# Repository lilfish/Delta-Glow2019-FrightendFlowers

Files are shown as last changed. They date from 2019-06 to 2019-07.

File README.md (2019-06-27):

# Glow-2019 - Frightend flowers

## Concept - the story

There was this biologist and he got bullied a lot when he was younger, the only way he found peace and comfort was by talking to his plants. The plants wouldn’t call him names or judge him.
 
But, after a while he got bored. He would share all his problems with the plants, but the plants couldn’t share theirs. He started to do experiments with the plants, with an effort to get to know the plants better.
 
After a while, he found a way to make the plants communicate with each other through light. The biologist now made visual what was going on with the plants; not only for the plants themselves but also for the eyes of the people.
 
While the biologist observed the communications, something strange happened. When the biologist was a few meters away, the plants would very calmly and rarely communicate with each other. But, when the biologist came close, the plants would go wild.
 
The biologist did not understand why and tried to figure it out. He put the plants on the floor close to his desk, and observe tirelessly until he knew what was going on.
 
After a while, he would notice something strange. When he was extremely close to a plant for a while, he noticed that that plants would suddenly stop communicating. It would take a while when they started again, and in the meantime, they wouldn’t grow. And then he knew.
 
The plants were terrified of him. Because they were afraid, they let each other know a human was near. 

The biologist was very shocked by this. So much that he decided he had to let the entire world know what was going on. This led to the creation of Frightened Flowers

## Concept - in depth

There will be multiple frames holding flower pots. Each flower pot will have a led strip to light up the flower and the pot on the outside/inside.

On top of the frame there is a motor that can lift the flower pot (with flower inside it) up and down. The motor is also able to shake the flower a bit when it's frightend.

There are also led strips sticking out of a flowerpot going to the next flower pot. These are "communication leds" and will visualize the effect of the plants talking to each other. The pots will light up or have another cool effect when a plant receives a "light pulse".

The flowers should probably also have a small vibration motor to vibrate the leaves and flower itself. This is to show the frightend effect.

## Documentation & workflow

All the documentation can be found in the git wiki found [here](https://git.fhict.nl/I393504/glow-2019/wikis/home)

As for the workflow: there are 4 main branches. These are

* Release
* Master
* Untested
* Others

**Release**\
When you have tested your code and it works on a frame and/or with multiple frames, you can move it to the Release. This is the code that will be uploaded to the arduinos. 

**Master**\
This will have all the final code, before getting tested for release.

**Untested**\
When you are done with an example code and want to intergrate it with the main code, you can add this to the untested. This code should be tested on a frame before moving to the Release folder.

**Others**\
This folder is for everything not code related. These can be presentation files, frame blueprints and the 3D case plans. For each item you can make a new folder and upload it in there. This way this project doesnt need a drive when giving it to other students.
In this folder you are also allowed to make new folders with your name. In the folder you just created you can store example code. These example codes are codes that can run on a arduino stand-alone, but not yet in the final version.

Currently we have two arduino's per frame. Thats why you can find two folders inside the Untested and Release folder. These are called ``motorSensorController`` and ``ledstripController``. The motorSensorController is the motor & sensor arduino. The ledstripController is the code for the arduino inside the flower pot which will emit light effects and such.

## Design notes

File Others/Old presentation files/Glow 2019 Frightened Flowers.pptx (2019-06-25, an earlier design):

## Glow 2019 Frightened Flowers

Davey Hurkmans, Geert Boer, Jane Buzykina & Vincent Venhuizen

## KNOWN PROBLEMS & FIXES

- Motor - Problems for demo
- Frame - Needs to be built more stable
- LED strips - Couldn't order new ones (re-used old one's)
- Animations - Require fine tuning

## DEMO

We start with a small demo of our project.

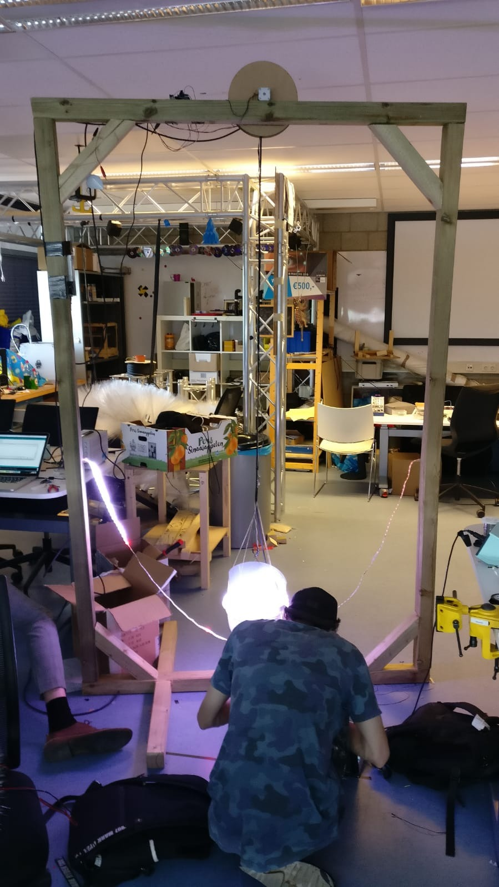
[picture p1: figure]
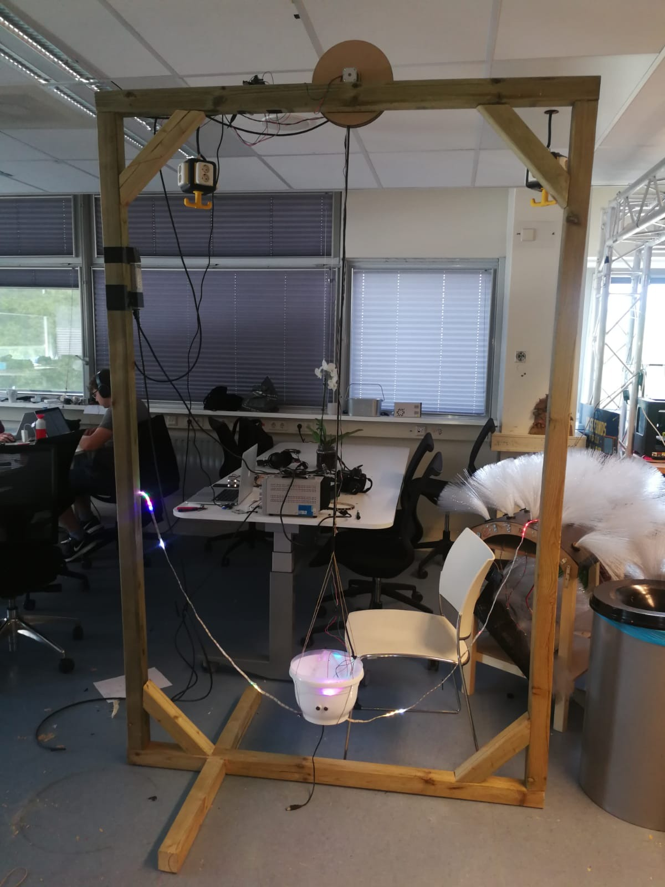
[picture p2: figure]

## COSTS

- Wooden frame - €60 +- /per frame
- LED strips 5M - €20 +- /1x
- Stepper motor - €40 +- /1x
- Power supply - €12 +- /1x
- Flower pot - €10 +- /1x
Total per frame: €140
I.e. 7 frames: €994

## Thanks for listening!

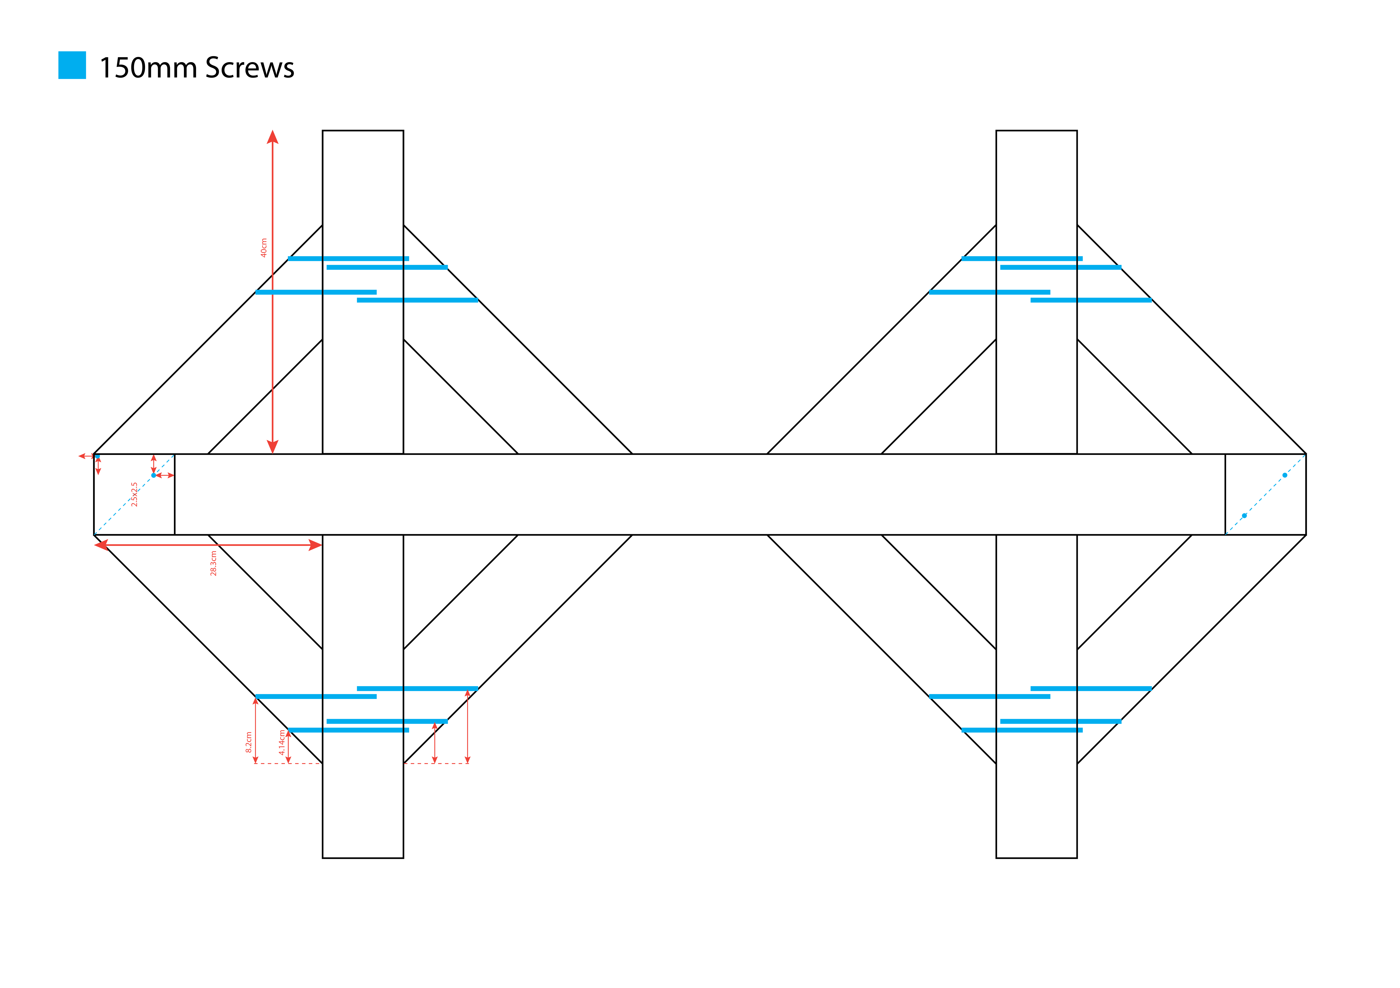
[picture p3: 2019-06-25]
Others/Frame blueprints/Frame blueprints - feet view.png

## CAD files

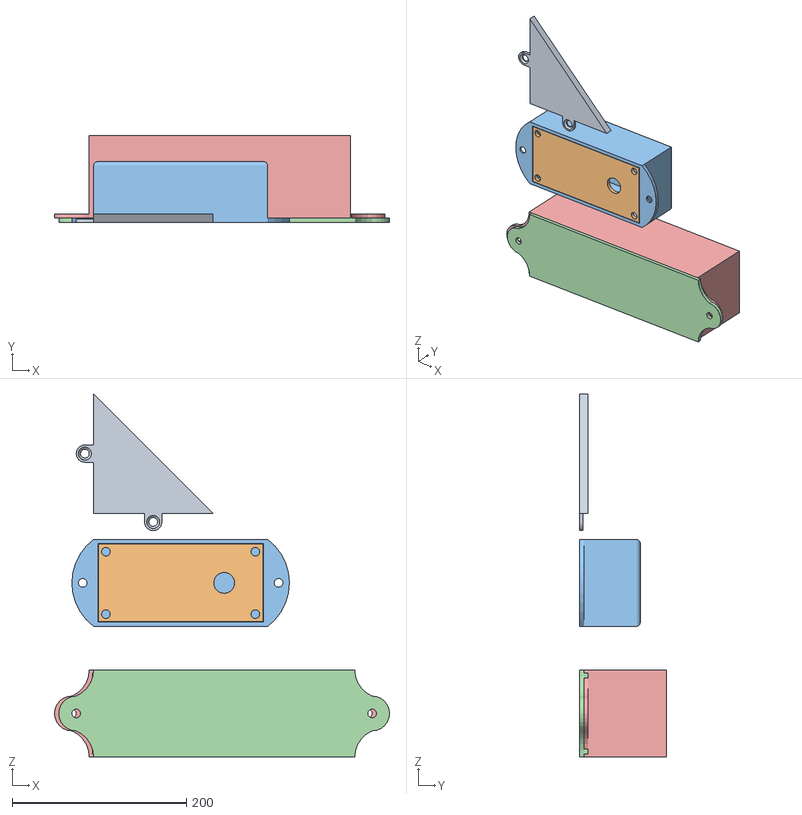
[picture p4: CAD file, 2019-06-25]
Others/Case plans (3D files)/Glow_casings v2.obj
385.0 x 100.0 x 417.0
Electronic case cap
motor_case_floor
motor_case_cap
powerSuply_floor
powerSuply_cap

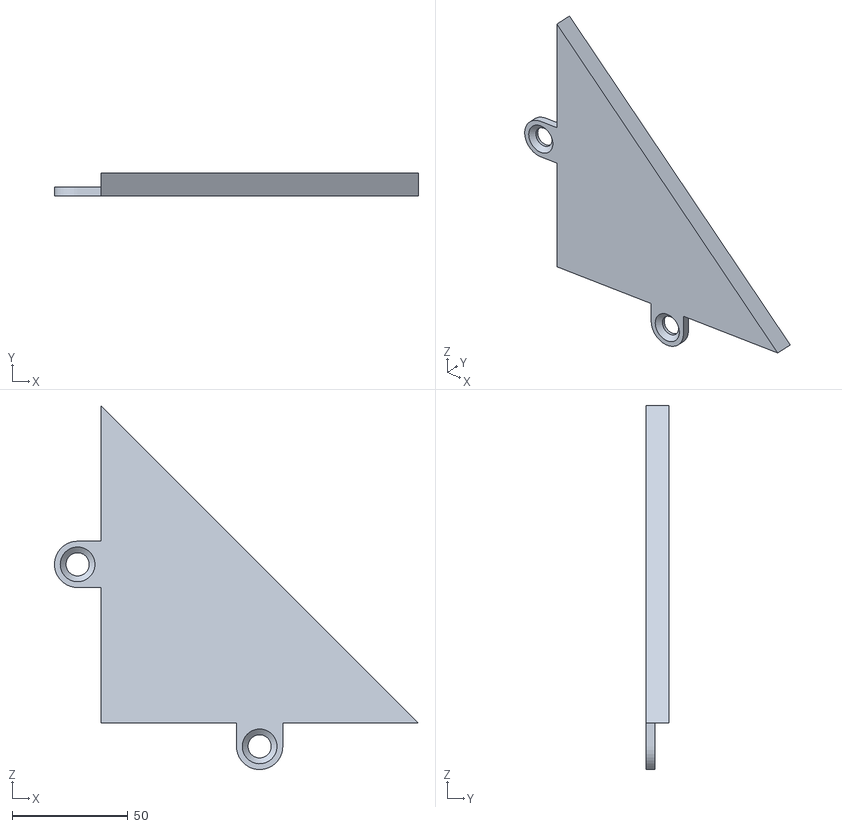
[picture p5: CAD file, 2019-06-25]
Others/Case plans (3D files)/STL files/Electronic case cap.stl
157.0 x 10.0 x 157.0

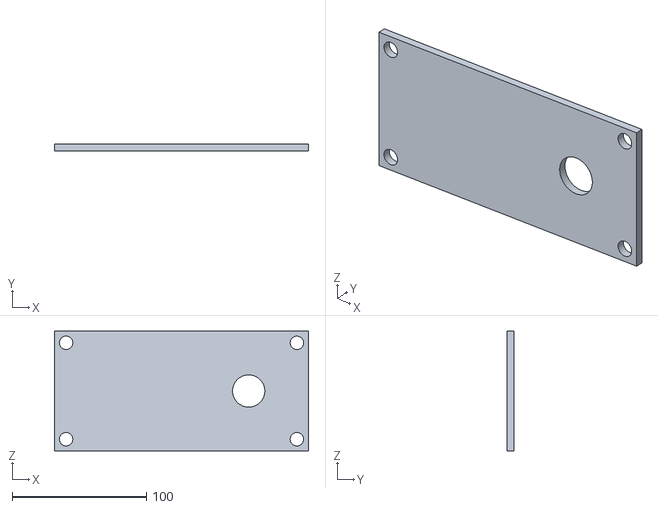
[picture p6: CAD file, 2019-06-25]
Others/Case plans (3D files)/STL files/motor_case_floor.stl
189.0 x 5.00 x 89.0

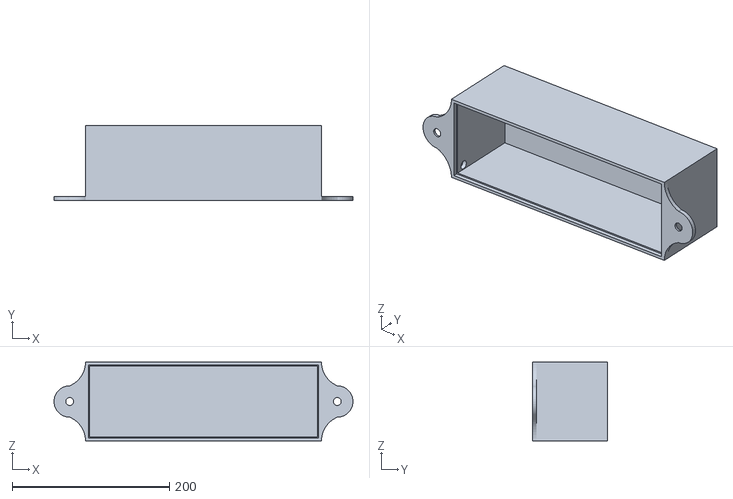
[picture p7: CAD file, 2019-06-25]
Others/Case plans (3D files)/STL files/powerSuply_cap.stl
380.0 x 95.0 x 100.0

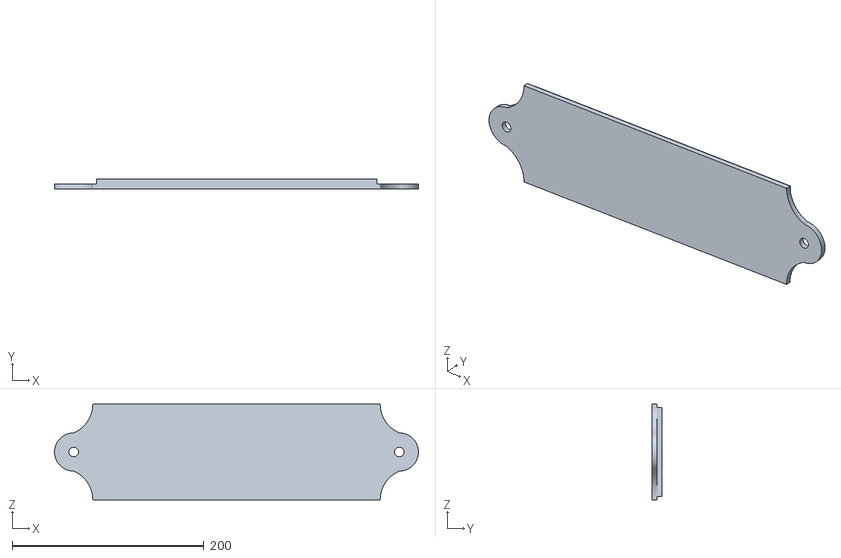
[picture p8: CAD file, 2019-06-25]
Others/Case plans (3D files)/STL files/powerSuply_floor.stl
380.0 x 10.0 x 100.0

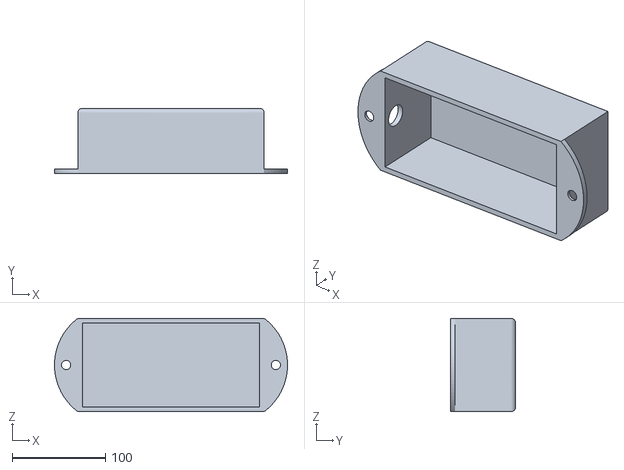
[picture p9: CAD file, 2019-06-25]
Others/Case plans (3D files)/STL files/motor_case_cap.stl
249.9 x 70.0 x 100.0

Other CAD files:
Others/Case plans (3D files)/Glow_casings v2.f3d

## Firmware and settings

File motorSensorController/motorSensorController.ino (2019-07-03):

#include "Enums.hpp"

#include "IMotor.hpp"
#include "StepperMotor.hpp"

StepperMotor motor(200, 8, 9, 10, 11);

int maxHeight = 2700;
void setup()
{
  // put your setup code here, to run once:
  Serial.begin(9600);
  motor.GoToHeight(maxHeight - 300);
}


void loop()
{
  motor.GoToHeight(maxHeight);
  delay(2000);
  motor.FallDown();
  motor.GoToHeight(maxHeight - 300);
  for (int i = 0; i < 40; i++)
  {
    motor.Shake(50);
  }
}

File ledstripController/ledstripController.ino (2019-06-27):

#define DEBUG

#include "Enums.hpp"

#include "ICommunicator.hpp"
#include "ILedstrip.hpp"
#include "IDistanceSensor.hpp"

#include "SerialCommunicator.hpp"
#include "WS2812Strip.hpp"
#include "UltrasonicDistanceSensor.hpp"

#define STRIP_SIZE 30
#define STRIP_PIN 12

ICommunicator* communicator;
ILedstrip* strip;

IDistanceSensor* sensor;



CRGB Leds[STRIP_SIZE];

void setup() {
  // put your setup code here, to run once:
  communicator = new SerialCommunicator(9600);
  sensor = new UltrasonicDistanceSensor(9, 10);

  FastLED.addLeds<WS2812B, STRIP_PIN, RGB>(Leds, STRIP_SIZE);

  
  strip = new WS2812Strip(Leds,STRIP_SIZE);

  #ifdef DEBUG
  Serial.println("Started");
  #endif
}


States state = UNINITIALIZED;
void loop() {
  // put your main code here, to run repeatedly:
  

  //check what state it should be in


  state = sensor->GetState();


  
  Serial.println(state);
  strip->SetState(state);
}

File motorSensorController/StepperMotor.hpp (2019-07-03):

#pragma once

#include "Enums.hpp"
#include <Stepper.h>

class StepperMotor
{
  private:
    Stepper* stepper;
    int currentHeight;

    int m1a;
    int m1b;
    int m2a;
    int m2b;
  public:
    StepperMotor(int stepsPerRev, int m1a, int m1b, int m2a, int m2b);
    void Update();
    void SetState(States state);
    float CalculateHeight(float restlesness);
    ~StepperMotor();

    bool GoToHeight(int height);
    int CurrentHeight();
    bool Shake(int intensity);
    void FallDown();
};

StepperMotor::StepperMotor(int stepsPerRev, int m1a, int m1b, int m2a, int m2b)
{
  stepper = new Stepper(stepsPerRev, m1a, m1b, m2a, m2b);
  stepper->setSpeed(170);

  pinMode(m1a, OUTPUT);
  pinMode(m1b, OUTPUT);
  pinMode(m2a, OUTPUT);
  pinMode(m2b, OUTPUT);

  this->m1a = m1a;
  this->m1b = m1b;
  this->m2a = m2a;
  this->m2b = m2b;

  currentHeight = 0;
}

StepperMotor::~StepperMotor()
{
  delete stepper;
}

bool StepperMotor::GoToHeight(int height)
{
  int posToMove = height - currentHeight;
  stepper->step(posToMove);
  currentHeight = height;
  return true;
}

bool StepperMotor::Shake(int intensity)
{
  stepper->step(intensity);
  stepper->step(-1 * intensity);
  return true;
}

int StepperMotor::CurrentHeight()
{
  return currentHeight;
}

void StepperMotor::FallDown()
{
  digitalWrite(m1a, LOW);
  digitalWrite(m1b, LOW);
  digitalWrite(m2a, LOW);
  digitalWrite(m2b, LOW);
  currentHeight = 0;
  delay(8000);
}

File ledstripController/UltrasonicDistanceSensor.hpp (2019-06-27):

#pragma once

#include "IDistanceSensor.hpp"
#include "Enums.hpp"

class UltrasonicDistanceSensor : public IDistanceSensor
{
private: //HIER STAAN JE VARIABELEN DIE OVER DE HELE CLASS BESCHIKBAAR MOETEN ZIJN, MAAR NIET ERBUITEN
    int trigPin;
    int echoPin;

    int sensitivity = 5;

    int restlessness = 0;

    float y;

    States oldState;
    

  
    States calculateState();
    int getDistance();

public: // HIER STAAND DE VARIABELEN DIE ZOWEL BINNEN ALS BUITEN DE CLASS BESCHIKBAAR MOETEN ZIJN
    int UpdateRestlessness(int distance);
    States GetState();
    UltrasonicDistanceSensor(int trigPin, int echoPin);
    ~UltrasonicDistanceSensor(); // <-- NEGEER DEZE MAAR VINCENT

};

UltrasonicDistanceSensor::UltrasonicDistanceSensor(int trigPin, int echoPin)
{
    this->trigPin = trigPin;
    this->echoPin = echoPin;
    pinMode(trigPin, OUTPUT);
    pinMode(echoPin, INPUT);
    oldState = UNINITIALIZED;
}

UltrasonicDistanceSensor::~UltrasonicDistanceSensor() {} // <-- NEGEER DEZE OOK MAAR VINCENT

int UltrasonicDistanceSensor::getDistance()
{
    //States currentState = CALM;
    digitalWrite(trigPin, LOW);
    delayMicroseconds(2);

    digitalWrite(trigPin, HIGH);
    delayMicroseconds(10);
    digitalWrite(trigPin, LOW);
    // DO STUFF
    long measuredDuration = pulseIn(echoPin, HIGH);

    float measuredDistance = measuredDuration * 0.034 / 2;
    // Prints the distance on the Serial Monitor
    return (int)measuredDistance;
}


int UltrasonicDistanceSensor::UpdateRestlessness(int distance)
{   // SEE WIKI FOR EXPLANATION: https://git.fhict.nl/I393504/glow-2019/wikis/%5BPROGRAMMING%5D-How-the-sensor-calculates-the-state
    if(oldState == UNINITIALIZED)
    {
        oldState = CALM;
    }

    if (distance <= 250)
    {
        y = sensitivity - (float(sensitivity) / 250 * distance);

        if (oldState == CALM)
        {
            restlessness += y;
        }
        else if (oldState == RESTLESS1)
        {
            restlessness += (y + 1);
        }
        else if (oldState == RESTLESS2)
        {
            restlessness += (y + 2);
        }
        else if (oldState == RESTLESS3)
        {
            restlessness += (y + 3);
        }
    }
    else if (restlessness > 0)
    {
        restlessness -= 4;
    }
    if (restlessness < 0)
    {
        restlessness = 0;
    }
    
    #ifdef DEBUG
    Serial.print("Calculaterestlessness @  restlessness: ");
    Serial.println(restlessness);
    Serial.print("Calculaterestlessness @  distance: ");
    Serial.println(distance);
    Serial.print("Calculaterestlessness @  state: ");
    Serial.println((States)oldState);
    Serial.println("");
    #endif

    return restlessness;
}

States UltrasonicDistanceSensor::calculateState()
{   // SEE WIKI FOR EXPLANATION: https://git.fhict.nl/I393504/glow-2019/wikis/%5BPROGRAMMING%5D-How-the-sensor-calculates-the-state

    if (restlessness < 0)
    {
        return CALM;
    }

    States newState = CALM;

    if (restlessness > 0 && restlessness <= 100)
    {
        newState = (States)CALM;
    }
    else if (restlessness > 100 && restlessness <= 200)
    {
        newState = (States)RESTLESS1;
    }
    else if (restlessness > 200 && restlessness <= 300)
    {
        newState = (States)RESTLESS2;
    }
    else if (restlessness > 300 && restlessness <= 400)
    {
        newState = (States)RESTLESS3;
    }
    else if (restlessness > 400)
    {
        newState = (States)OUT;
    }

    oldState = newState;
    return newState;
}

States UltrasonicDistanceSensor::GetState()
{
    int distance = getDistance();
    UpdateRestlessness(distance);
    // private restlessness is updated and used by calculateState
    States state = calculateState();
    return state;
}

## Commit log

2019-06-17 Old demo code
    it pushes 2 leds colored over the led strip
2019-06-17 ledstripcontroller code added
2019-06-17 Worked on communication for ledstrip
    Only the return currentstate not working yet
    [ledstripController.ino, motorSensorController.ino]
2019-06-17 Fixed communication on mega
    Listen to Serial1 for input from the arduino uno.
    Changes state when input contains "s + int(1-5)"
    [motorSensorController.ino]
2019-06-17 Big update on motorSensorController
    Added debug mode
    Added the hc-srd1 read function in the Distance class
    Added a restless function in the Distance class
    Added a calculation function in the Motor class
2019-06-18 Worked on the led strip communication
    Communication broke, fixed but don't know why it broke.
    Added a big comment in ledstripController/ledstripController.ino - Check it please
    [WS2812Strip.hpp, ledstripController.ino]
2019-06-25 Fixed detection module
    Added an example sensor code. In here I made the concept and tested it with a potmeter.
    Added the final code from example to the main code in Release.
    [SensorCode.ino]
2019-06-25 Removed the ledstrip files from motor
    Ledstrips are not used in the motor arduino code. Removed these
2019-06-25 Added others folder
    In others you can find the presentation files, frame blueprints and 3D models
    Added a readme for this folder so it's clear where we use it for.
    [Electronic case cap.stl, Glow_casings v2.f3d, Glow_casings v2.obj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]
2019-06-27 Few updates on led and motor controller
    Moved the ultrasone code to the ledstrip controller.
    Changed the "calculate state" in to a function
    Added debug mode to ledstrip
2019-06-27 Schoonmaak crew fixup; compiles
    [UltrasonicDistanceSensor.hpp, ledstripController.ino, motorSensorController.ino]
2019-07-03 Stepper code finished :}
